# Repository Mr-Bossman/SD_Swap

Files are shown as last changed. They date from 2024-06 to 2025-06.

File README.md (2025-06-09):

# SD_Swap

## A development tool which swaps an SD card between a USB3 card reader and a SBC.

### About

SD_Swap allows reflashing of an SD card connected to the DUT (Device Under Test), without physical contact with the device. The board is designed in such way that it fits into micro SD card slots. Thanks to this, there is no need for special cables with a micro SD adapter, though it may be beneficial to add an extention to avoid accidentally breaking your boards SD connector if someone yanks the cable.

This project was inspired by the [SDWire](https://wiki.tizen.org/SDWire) project.
The major improvements are:
- USB-C
- USB3.0 read/write speeds
- Simplified design/control
- Solder jumpers to disconnect LEDs
- Dim LEDs so you wont get blinded

I have got SD write speeds up to 65MiB/s so 520Mbit/s

**IMPORTANT**

Faster SD cards may not work on some single board computers as the
timing and capacitance on the SBC side is not right.

### Rational

After seeing the [SDWire](https://wiki.tizen.org/SDWire) project I was disappointed by the complexity as well as the lack of USB3. So this project is uses the REALTEK RTS5306E controller which many USB3 to SD adapters use. The chip has power suspend functionality which we can use as a GPIO for switching hosts. The suspend option will shut off the SD cards power but not the controllers; it also has build-in RW protection as to finish writes before switching to the SBC

The SDWire project uses a USB to GPIO chip for this, but they have two power controlled USB ports on the board as well as the above mentioned method.

### Software
To swap the SD card between the host PC and the SBC you run
`sdswap -t` or `sdswap -c`.

 `-c` is the host PC while `-t` is the SBC. You can also chose which device to use if you have multiple attached. To do this run `lsusb` to show available the devices and type `sdswap -a 1-4 -c` in the format of `busNumber-deviceNumber`. I have future plans to write this script for Windows.

```
$ sdswap -h
Usage: sdswap [-h] [-p] [-c | -t] [-l location] [-a address] [-s serial] [-i VID:PID]
  -h, --help          Show this help message.
  -p, --print         Prints the block device
  -c, --controller    Switches to PC.
  -t, --target        Switchest to target.
  -l, --location      Set location.
  -a, --address       Set address.
  -s, --serial        Serial number.
  -i, --id            Set the PID and VID.
  -e, --exact         Use exact location.
If no options are given, the script will print the current status of the SDswap device.
If --print and --controller are given at the same time, the script will wait for the
SDswap device to be attached to the PC and then print the block device path.

Examples:
# sdswap
SDswap is attached to PC.

# sdswap -p
/dev/sda

# sdswap 0
Multiple devices found.

# sdswap -l 3-1.1 -t

# sdswap -a 3-19 -pc
/dev/sda
```

To manually controll the port use:

```
export YOUR_USB_NUM="1-4" #hub1 port4
echo 0 | sudo tee /sys/bus/usb/devices/${YOUR_USB_NUM}/power/autosuspend_delay_ms
echo auto | sudo tee /sys/bus/usb/devices/${YOUR_USB_NUM}/power/control

echo SBC
echo ${YOUR_USB_NUM} | sudo tee /sys/bus/usb/drivers/usb/unbind

echo PC
echo ${YOUR_USB_NUM} | sudo tee /sys/bus/usb/drivers/usb/bind
```
### Hardware
#### LEDs
 - D2 is the **red/blue** status LED it will be **blue** when the in passthrough mode, and **red** when the USB3 controller is reading/writing to it.
 - D1 is the **yellow** activity LED and blinks when the USB3 controller is reading/writing.
 - D3 is the **red** power LED and is active when the USB3 controller has power.

 **NOTE**: The **red** power LED will not be on if the USB cable isn't 5V providing power.

Front image of PCB
Back image of PCB
<!--
![Front image of rendered PCB](https://github.com/Mr-Bossman/SD_Swap/blob/master/images/Rendered_Front.jpg?raw=true)
![Back image of rendered PCB](https://github.com/Mr-Bossman/SD_Swap/blob/master/images/Rendered_Back.jpg?raw=true)
-->

### TODO
 - Fix SBC side timeing
 - Write program for Windows.
 - Fix serial number not working
 - Edit pick n' place csv
 - Label stat leds
 - Add use switching regulator
 - Add E-Fuse
 - Update readme

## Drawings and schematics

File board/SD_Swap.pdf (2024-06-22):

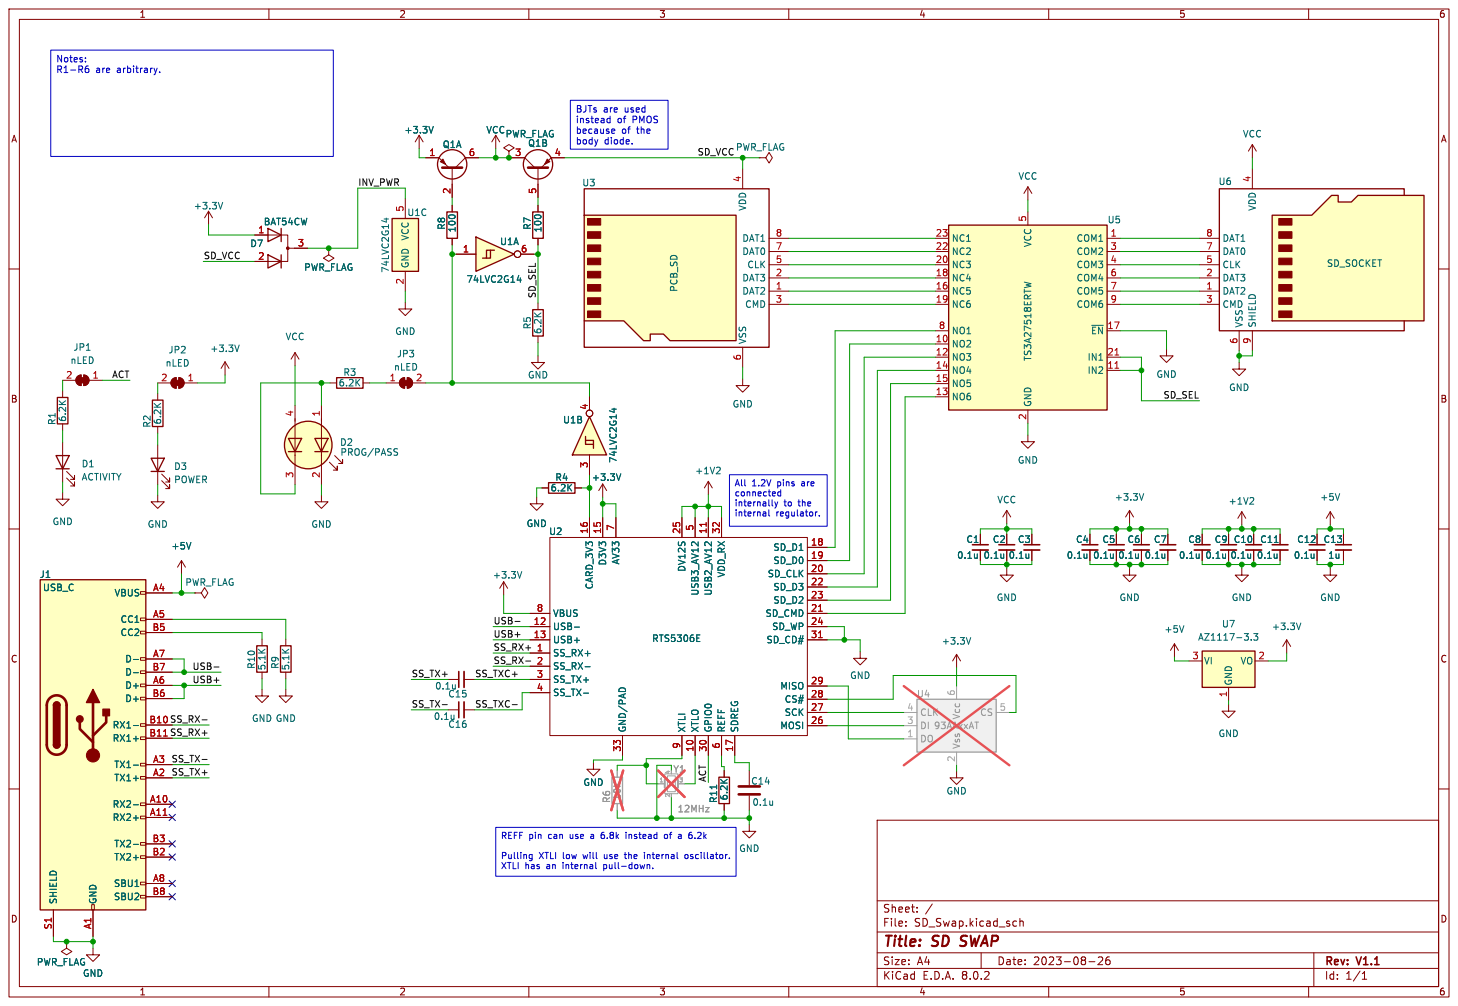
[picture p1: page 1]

1 VO 2 VI 3 U7 AZ1117-3.3 GND GND R7 100 +3.3V GND

3 4 U1B 74LVC2G14 SS_RX+ 1 XTLO 10 USB2_AV12 11 USB- 12 USB+ 13 D3V3 15 CARD_3V3 16 SDREG 17 SD_D1 18 SD_D0 19 SS_RX- 2 SD_CLK 20 SD_CMD 21 SD_D3 22 SD_D2 23 SD_WP 24 DV12S 25 MOSI 26 SCK 27 CS# 28 MISO SS_TX+ 29

Id: 1/1 Title: SD SWAP

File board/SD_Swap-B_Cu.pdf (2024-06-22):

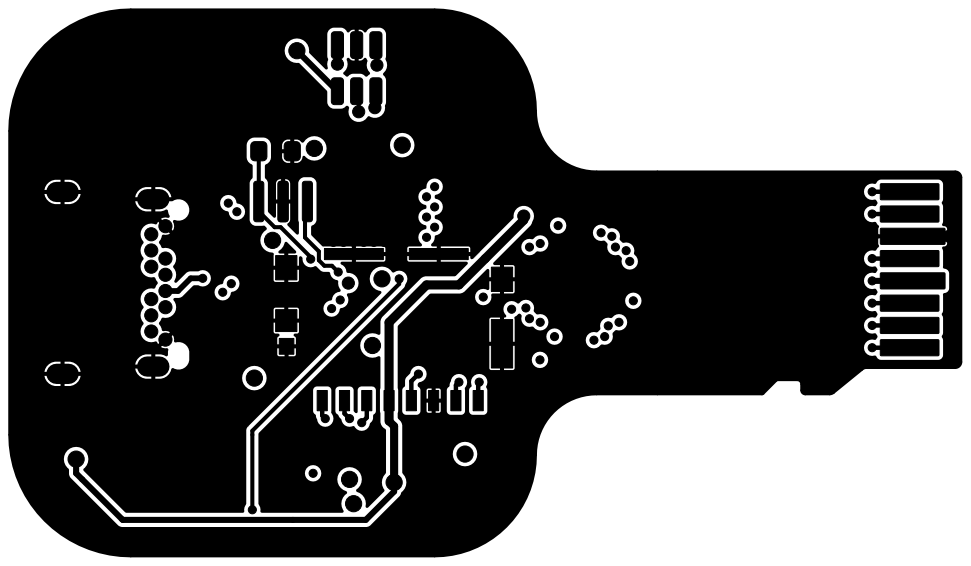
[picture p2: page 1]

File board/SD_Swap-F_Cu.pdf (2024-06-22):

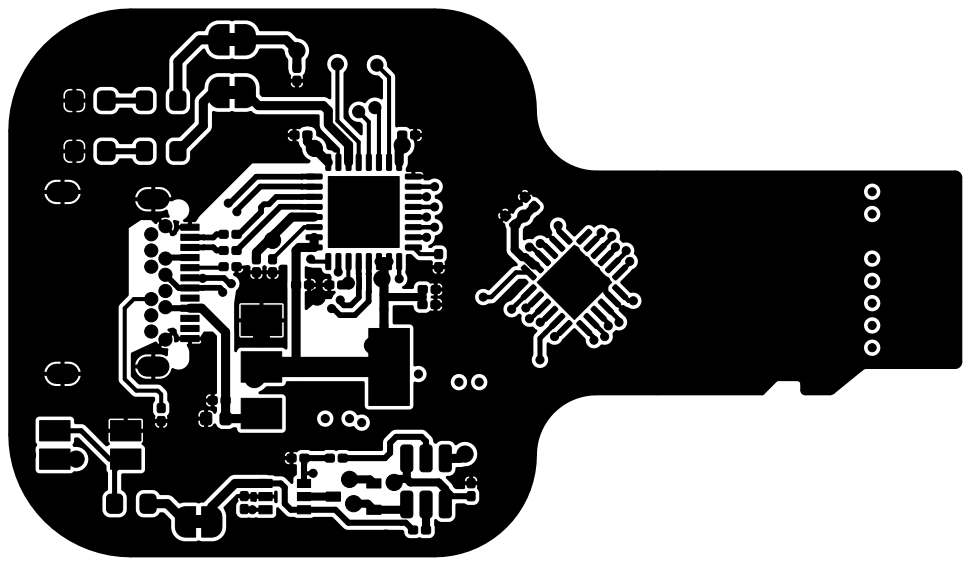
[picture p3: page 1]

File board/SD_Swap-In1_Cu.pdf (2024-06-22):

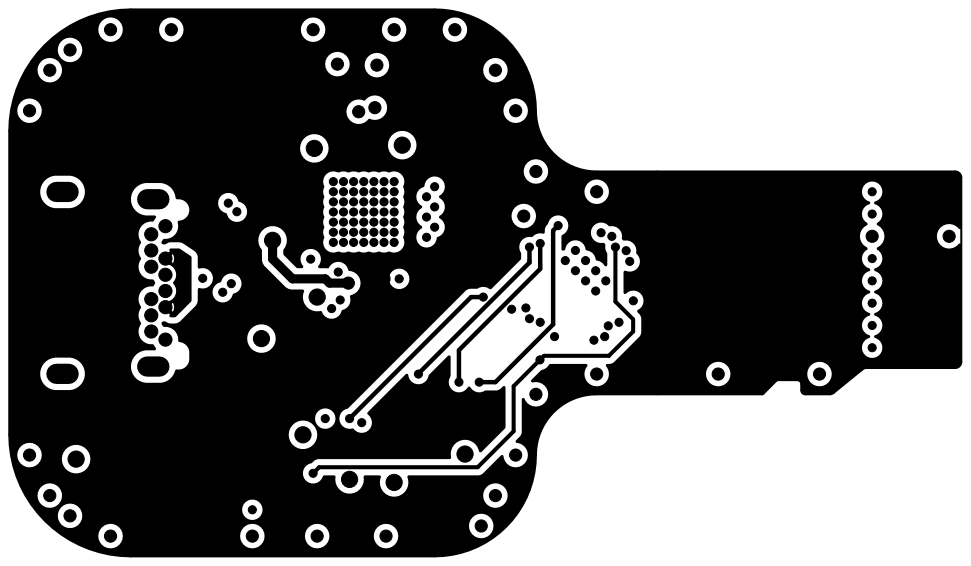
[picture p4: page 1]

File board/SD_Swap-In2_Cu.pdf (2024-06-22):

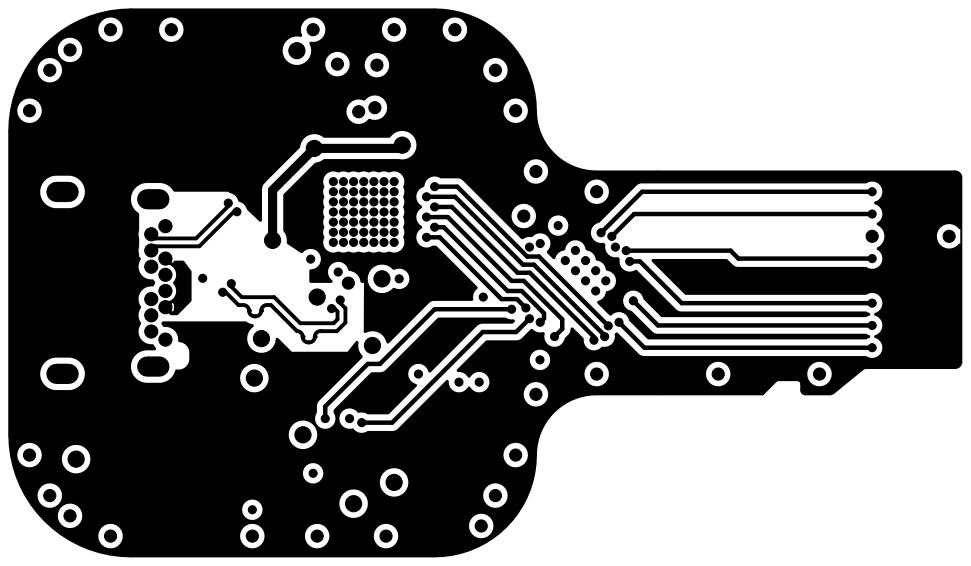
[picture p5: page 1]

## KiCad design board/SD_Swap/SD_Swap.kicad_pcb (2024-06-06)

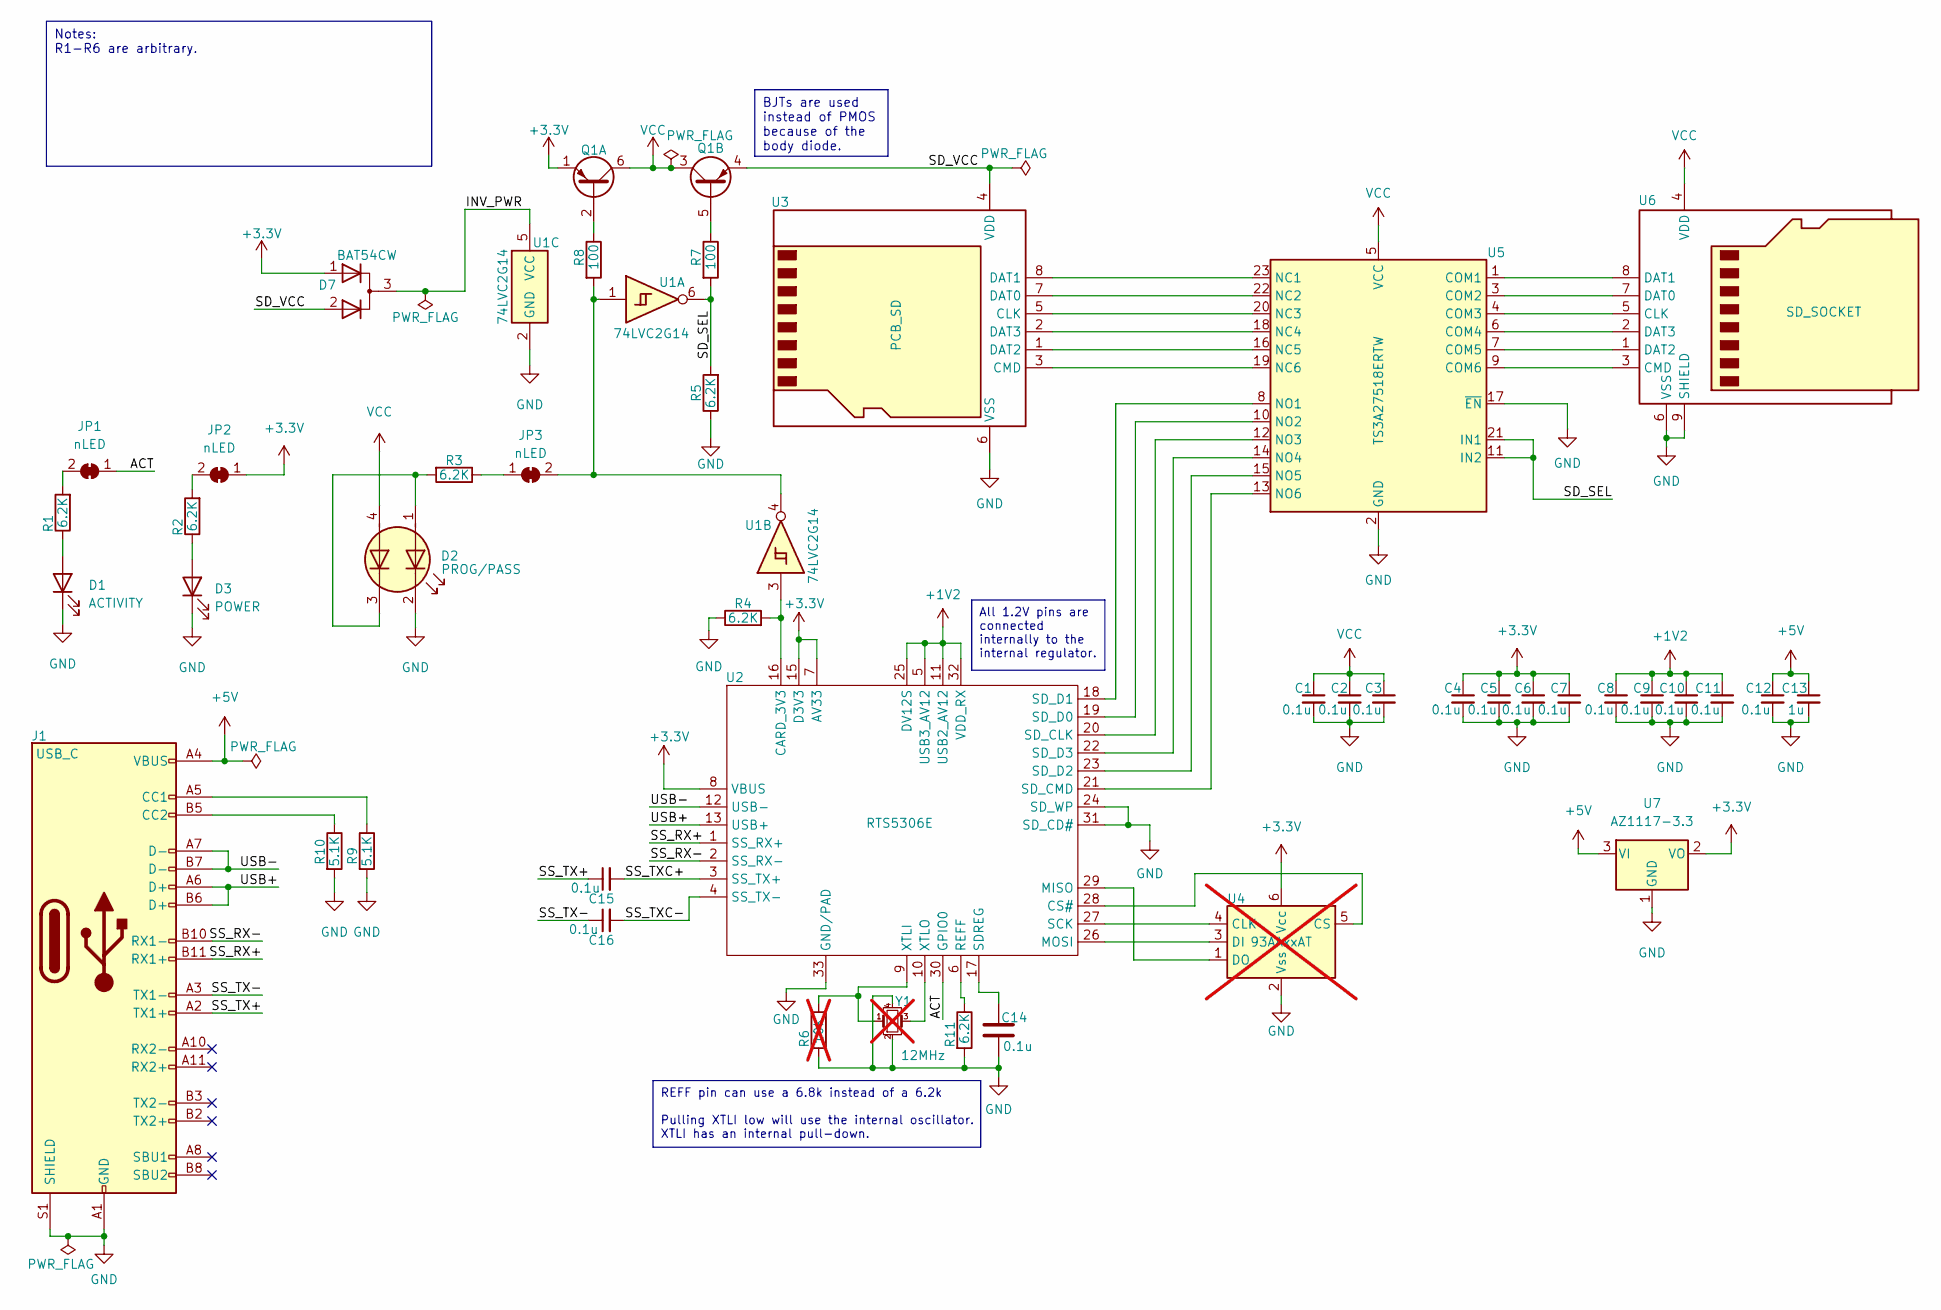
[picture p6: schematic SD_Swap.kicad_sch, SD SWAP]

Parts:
C1, C2, C3, C4, C5, C6, C7, C8, C9, C10, C11, C12, C14, C15, C16: 0.1u; C_0201_0603Metric; LCSC C66938
C13: 1u; C_0402_1005Metric; LCSC C107372
D1: ACTIVITY; LED_0603_1608Metric; LCSC C253534
D2: PROG/PASS; LED_RGB_1210; LCSC C264332
D3: POWER; LED_0603_1608Metric; LCSC C434419
D7: BAT54CW; SOT-323_SC-70; Part Number BAT54CW; LCSC C57891
J1: USB_C; USB_C_Receptacle_Amphenol_10137061-00021LF; Part Number 10137061-00021LF; LCSC C3197967
JP1, JP2, JP3: nLED; SolderJumper-2_P1.3mm_Bridged_RoundedPad1.0x1.5mm; Part Number NONE
Q1: Q_Dual_PNP_PNP_E1B1C2E2B2C1; SOT-23-6; Part Number QST8TR; LCSC C703623
R1, R2, R3: 6.2K; R_0603_1608Metric; LCSC C4260
R4, R5, R11: 6.2K; R_0201_0603Metric; LCSC C423334
R6: 10K; R_0603_1608Metric; not fitted
R7, R8: 100; R_0201_0603Metric; LCSC C2991668
R9, R10: 5.1K; R_0201_0603Metric; LCSC C100142
U1: 74LVC2G14; SOT-363_SC-70-6; Part Number 74LVC2G14; LCSC C3294721
U2: RTS5306E; VQFN-32-1EP_5x5mm_P0.5mm_EP3.5x3.5mm; Part Number RTS5306E; LCSC C2848856
U3: PCB_SD; PCB-SD; Part Number NONE
U4: 93AAxxAT; SOT-23-6; Part Number 93AA86AT; not fitted
U5: TS3A27518ERTW; WQFN-24-1EP_4x4mm_P0.5mm_EP2.6x2.6mm; Part Number TS3A27518ERTW; LCSC C2651937
U6: SD_SOCKET; 105162-0001; Part Number 105162-0001
U7: AZ1117-3.3; SOT-223-3_TabPin2; Part Number AZ1117CH-3.3TRG1; LCSC C92102
Y1: 12MHz; Resonator-3.2x1.3mm; Part Number CSTNE12M0G55A000R0; LCSC C907940; not fitted

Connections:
+1V2: C8.1, C9.1, C10.1, C11.1, U2.5 (USB3_AV12), U2.11 (USB2_AV12), U2.25 (DV12S), U2.32 (VDD_RX)
+3.3V: C4.1, C5.1, C6.1, C7.1, D7.1 (K), JP2.1 (A), Q1.1 (E1), U2.7 (AV33), U2.8 (VBUS), U2.14 (VBUS), U2.15 (D3V3), U4.6 (Vcc), U7.2 (VO)
+5V: C12.1, C13.1, J1.A4 (VBUS), J1.A9 (VBUS), J1.B4 (VBUS), J1.B9 (VBUS), U7.3 (VI)
/ACT: JP1.1 (A), U2.30 (GPIO0)
/INV_PWR: D7.3 (A), U1.5 (VCC)
/SD_SEL: R5.2, R7.2, U1.6, U5.11 (IN2), U5.21 (IN1)
/SD_VCC: D7.2 (K), Q1.4 (E2), U3.4 (VDD)
/SS_RX+: J1.B11 (RX1+), U2.1 (SS_RX+)
/SS_RX-: J1.B10 (RX1-), U2.2 (SS_RX-)
/SS_TX+: C15.1, J1.A2 (TX1+)
/SS_TX-: C16.1, J1.A3 (TX1-)
/SS_TXC+: C15.2, U2.3 (SS_TX+)
/SS_TXC-: C16.2, U2.4 (SS_TX-)
/USB+: J1.A6 (D+), J1.B6 (D+), U2.13 (USB+)
/USB-: J1.A7 (D-), J1.B7 (D-), U2.12 (USB-)
GND: C1.2, C2.2, C3.2, C4.2, C5.2, C6.2, C7.2, C8.2, C9.2, C10.2, C11.2, C12.2, C13.2, C14.2, D1.1 (K), D2.2 (K1), D3.1 (K), J1.A1 (GND), J1.A12 (GND), J1.B1 (GND), J1.B12 (GND), J1.S1 (SHIELD), R4.1, R5.1, R6.2, R9.2, R10.2, R11.2, U1.2 (GND), U2.24 (SD_WP), U2.31 (SD_CD#), U2.33 (GND/PAD), U3.6 (VSS), U4.2 (Vss), U5.2 (GND), U5.17 (~EN), U5.25 (GND), U6.6 (VSS), U6.9 (SHIELD), U6.10 (SHIELD), U6.11 (SHIELD), U6.12 (SHIELD), U6.13 (SHIELD), U6.14 (SHIELD), U6.15 (SHIELD), U7.1 (GND), Y1.2, Y1.4
unnamed: D1.2 (A), R1.1
unnamed: D2.1 (A1), D2.3 (K2), R3.2
unnamed: D3.2 (A), R2.1
unnamed: J1.A5 (CC1), R9.1
unnamed: J1.B5 (CC2), R10.1
unnamed: JP1.2 (B), R1.2
unnamed: JP2.2 (B), R2.2
unnamed: JP3.1 (A), R3.1
unnamed: JP3.2 (B), R8.2, U1.1, U1.4
unnamed: Q1.2 (B1), R8.1
unnamed: Q1.5 (B2), R7.1
unnamed: R4.2, U1.3, U2.16 (CARD_3V3)
unnamed: U2.28 (CS#), U4.5 (CS)
unnamed: U2.29 (MISO), U4.1 (DO)
unnamed: U2.26 (MOSI), U4.3 (DI)
unnamed: R11.1, U2.6 (REFF)
unnamed: U2.27 (SCK), U4.4 (CLK)
unnamed: C14.1, U2.17 (SDREG)
unnamed: U2.20 (SD_CLK), U5.12 (NO3)
unnamed: U2.21 (SD_CMD), U5.13 (NO6)
unnamed: U2.19 (SD_D0), U5.10 (NO2)
unnamed: U2.18 (SD_D1), U5.8 (NO1)
unnamed: U2.23 (SD_D2), U5.15 (NO5)
unnamed: U2.22 (SD_D3), U5.14 (NO4)
unnamed: R6.1, U2.9 (XTLI), Y1.1
unnamed: U2.10 (XTLO), Y1.3
unnamed: U3.5 (CLK), U5.20 (NC3)
unnamed: U3.3 (CMD), U5.19 (NC6)
unnamed: U3.7 (DAT0), U5.22 (NC2)
unnamed: U3.8 (DAT1), U5.23 (NC1)
unnamed: U3.1 (DAT2), U5.16 (NC5)
unnamed: U3.2 (DAT3), U5.18 (NC4)
unnamed: U5.1 (COM1), U6.8 (DAT1)
unnamed: U5.3 (COM2), U6.7 (DAT0)
unnamed: U5.4 (COM3), U6.5 (CLK)
unnamed: U5.6 (COM4), U6.2 (DAT3)
unnamed: U5.7 (COM5), U6.1 (DAT2)
unnamed: U5.9 (COM6), U6.3 (CMD)
VCC: C1.1, C2.1, C3.1, D2.4 (A2), Q1.3 (C2), Q1.6 (C1), U5.5 (VCC), U6.4 (VDD)

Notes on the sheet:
Notes: R1-R6 are arbitrary.
BJTs are used instead of PMOS because of the body diode.
All 1.2V pins are connected internally to the internal regulator.
REFF pin can use a 6.8k instead of a 6.2k Pulling XTLI low will use the internal oscillator. XTLI has an internal pull-down.

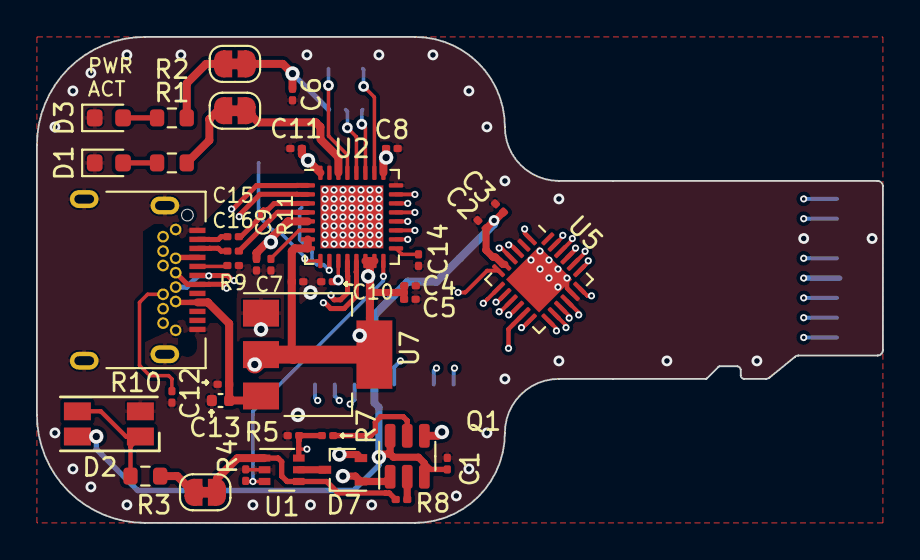
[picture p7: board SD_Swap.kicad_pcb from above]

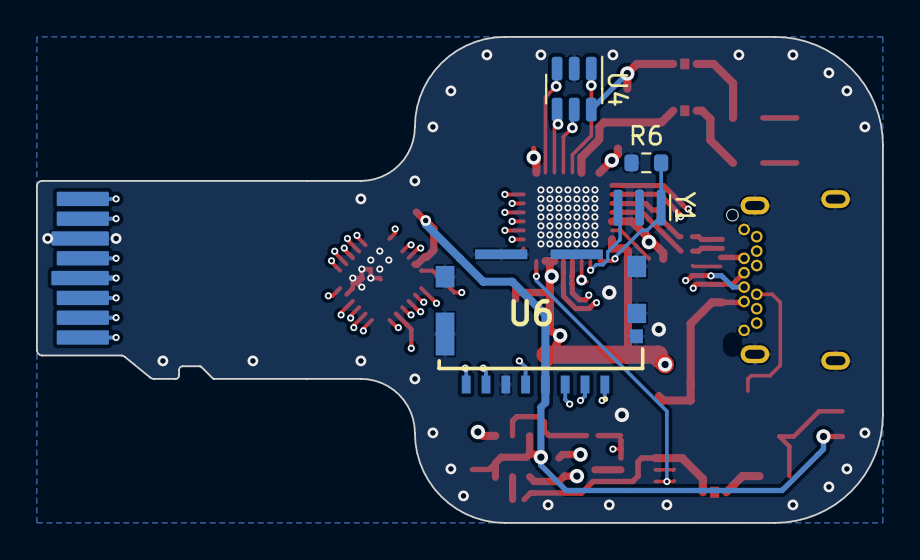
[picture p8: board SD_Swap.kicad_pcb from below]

Board: 4 copper layers, 47.0 x 27.0 mm, 44 parts (4 on the bottom side), 55 nets.

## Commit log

2022-12-16 Golden release candidate
    [SD_Swap.kicad_pcb, SD_Swap.kicad_sch]
2022-12-16 half way done with sch
    [SD_Swap.kicad_sch]
2022-12-16 done with sch
    [SD_Swap.kicad_sch]
2022-12-16 working on pcb add some caps to sch
    [SD_Swap.kicad_pcb, SD_Swap.kicad_sch]
2022-12-17 mostly done with the usb side of the brd
    [SD_Swap.kicad_pcb, SD_Swap.kicad_sch]
2022-12-17 doing more brd
    [SD_Swap.kicad_pcb, SD_Swap.kicad_sch]
2022-12-18 more sch and swap component sizes
    [SD_Swap.kicad_sch]
2022-12-18 fix gerber folder
2022-12-18 add pcb-sd footprint add some notes in the sch
    [SD_Swap.kicad_pcb, SD_Swap.kicad_sch]
2022-12-19 add board mostly done
    [SD_Swap.kicad_pcb, SD_Swap.kicad_sch]
2022-12-19 add sdcard holder
    [SD_Swap.kicad_pcb, SD_Swap.kicad_sch]
2022-12-19 more routing
    [SD_Swap.kicad_pcb]
2022-12-20 more routing change osc and remove extra cap
    [SD_Swap.kicad_pcb, SD_Swap.kicad_sch]
2022-12-20 done with routing
    [SD_Swap.kicad_pcb]
2022-12-20 update BOM
    [SD_Swap.kicad_pcb, SD_Swap.kicad_sch]
2022-12-31 update fix led
    [SD_Swap.csv, SD_Swap.kicad_pcb, SD_Swap.kicad_sch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]
2023-02-24 fixed clearance issue pnp base resistor is now 100R
    [SD_Swap.kicad_pcb, SD_Swap.kicad_sch]
2023-02-26 update sch
    [SD_Swap.kicad_sch]
2023-03-26 add bigger reg to sch, update BOM,update todo
    [SD_Swap.kicad_sch]
2023-09-01 update sch to use diodes to power the inverter
    [SD_Swap.kicad_sch]
2023-09-01 update PCB to fix USB3 issues
    [SD_Swap.csv, SD_Swap.kicad_pcb, SD_Swap.kicad_sch]
2023-09-01 add images and pdfs
    [SD_Swap.csv]
2023-09-01 export gerber
    [SD_Swap.kicad_pcb]
2023-12-09 I did USB-C wrong in the stupidest way
    [SD_Swap.kicad_sch]
2023-12-12 tmp fix for my mistake
    [SD_Swap.kicad_pcb, SD_Swap.kicad_sch]
2024-01-15 fix usbc
    [SD_Swap.kicad_pcb]
2024-01-24 remove pos files
    [SD_Swap-bottom-pos.csv, SD_Swap-top-pos.csv]
2024-06-06 update to kicad 8
    [SD_Swap.kicad_pcb, SD_Swap.kicad_sch]
2024-06-06 update transistor
    [SD_Swap.kicad_sch]
2024-10-24 fix print
2025-06-09 sdswap: Add C version of sdswap program
    The C version allows for the control of the SDswap device
    on macOS and Linux systems.
